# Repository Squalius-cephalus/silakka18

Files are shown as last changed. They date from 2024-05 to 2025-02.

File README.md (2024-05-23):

# Silakka18
RP2040 based macropad with hotswap sockets. Microcontroller uses QMK firmware with Vial support. Based on the [Silli18](https://github.com/Squalius-cephalus/silli18 "Silli18") project, but the firmware is not compatible between them.

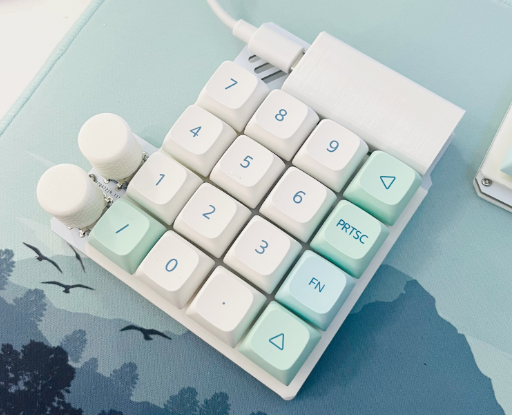
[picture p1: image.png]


## Bill of materials

 - 1 x PCB
 - 1 x Pin compatible Raspberry Pi Pico
 - 1 x 3D printed bottom plate
 - 1 x 3D printed top plate
 - 2 x EC11 Rotary encoders
 - 16 x MX style mechanical switches
 - 16 x MX compatible keycaps
 - 16 x Kailh Hotswap Sockets
 - 8 x M2 4mm bolt
 - 8 x M2 brass inserts 
 - 8x Rubber feet

## TODO

 1. Make build guide

PCB design uses footprints from [ScottoKeebs](https://github.com/joe-scotto/scottokeebs/tree/main/Extras/ScottoKicad "ScottoKeebs") and [kbd library.](https://github.com/foostan/kbd "kbd library.")

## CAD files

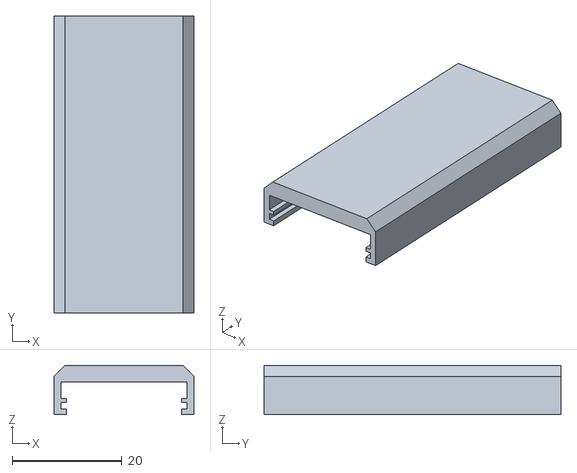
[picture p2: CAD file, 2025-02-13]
stl/raspberry_pi_pico_cover.stl
25.4 x 54.0 x 9.00

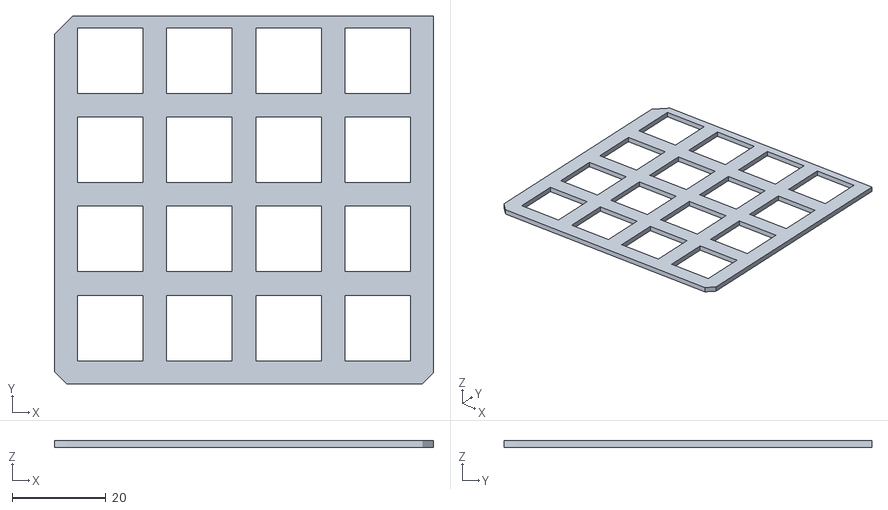
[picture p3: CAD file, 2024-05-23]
stl/silakka18_top.stl
81.0 x 78.5 x 1.50

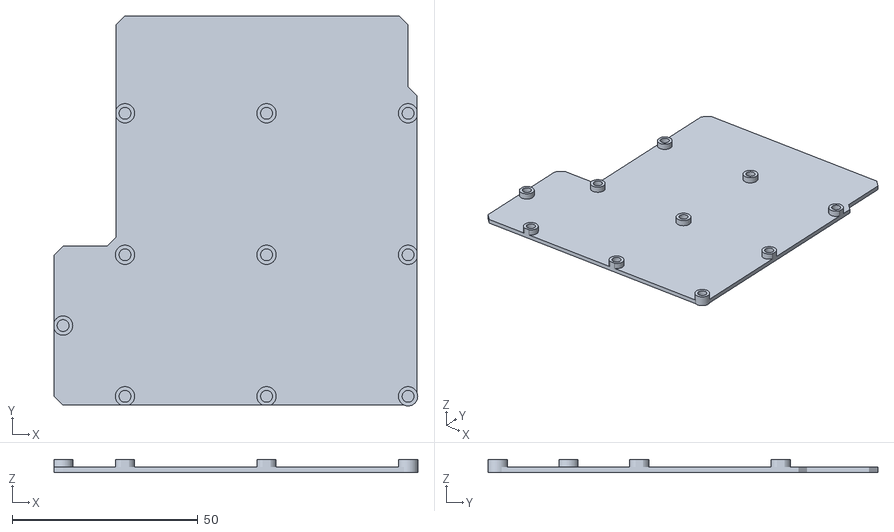
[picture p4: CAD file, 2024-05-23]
stl/silakka18_bottom.stl
97.9 x 105.0 x 3.57

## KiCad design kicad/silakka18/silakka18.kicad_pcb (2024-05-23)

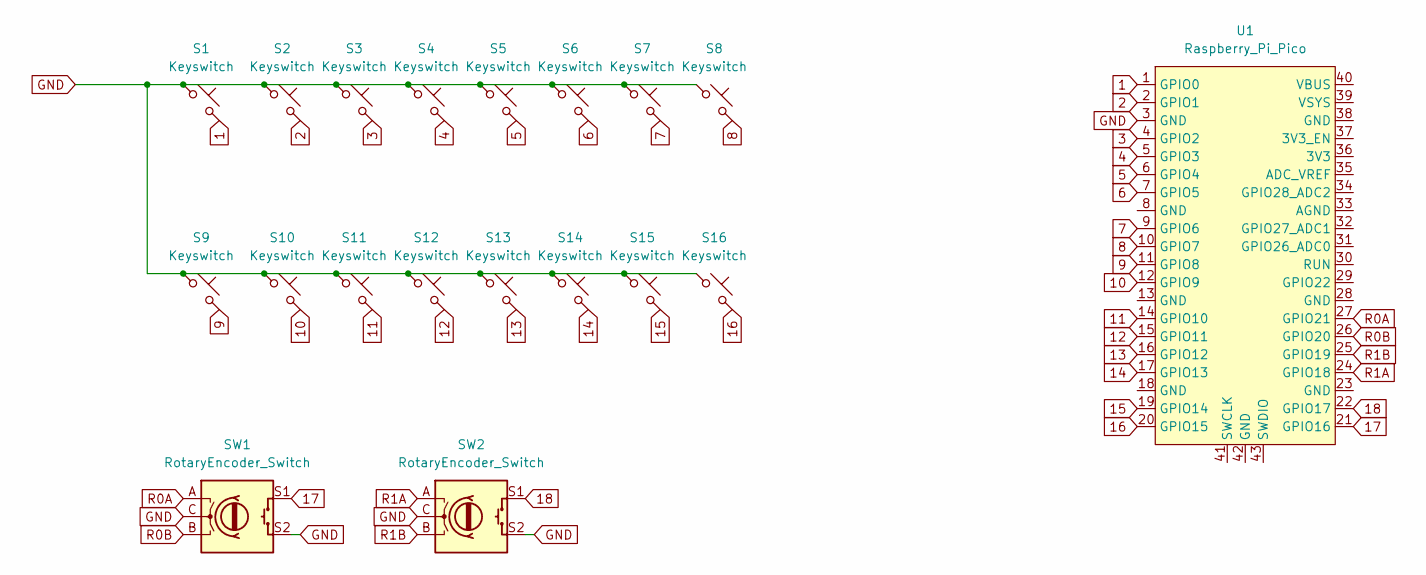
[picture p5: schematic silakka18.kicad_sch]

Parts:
S1, S2, S3, S4, S5, S6, S7, S8, S9, S10, S11, S12, S13, S14, S15, S16: Keyswitch; CherryMX_Hotswap
SW1, SW2: RotaryEncoder_Switch; RotaryEncoder_EC11
U1: Raspberry_Pi_Pico

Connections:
1: S1.2, U1.1 (GPIO0)
2: S2.2, U1.2 (GPIO1)
3: S3.2, U1.4 (GPIO2)
4: S4.2, U1.5 (GPIO3)
5: S5.2, U1.6 (GPIO4)
6: S6.2, U1.7 (GPIO5)
7: S7.2, U1.9 (GPIO6)
8: S8.2, U1.10 (GPIO7)
9: S9.2, U1.11 (GPIO8)
10: S10.2, U1.12 (GPIO9)
11: S11.2, U1.14 (GPIO10)
12: S12.2, U1.15 (GPIO11)
13: S13.2, U1.16 (GPIO12)
14: S14.2, U1.17 (GPIO13)
15: S15.2, U1.19 (GPIO14)
16: S16.2, U1.20 (GPIO15)
17: SW1.S1, U1.21 (GPIO16)
18: SW2.S1, U1.22 (GPIO17)
GND: S1.1, S2.1, S3.1, S4.1, S5.1, S6.1, S7.1, S8.1, S9.1, S10.1, S11.1, S12.1, S13.1, S14.1, S15.1, S16.1, SW1.C, SW1.S2, SW2.C, SW2.S2, U1.3 (GND)
R0A: SW1.A, U1.27 (GPIO21)
R0B: SW1.B, U1.26 (GPIO20)
R1A: SW2.A, U1.24 (GPIO18)
R1B: SW2.B, U1.25 (GPIO19)

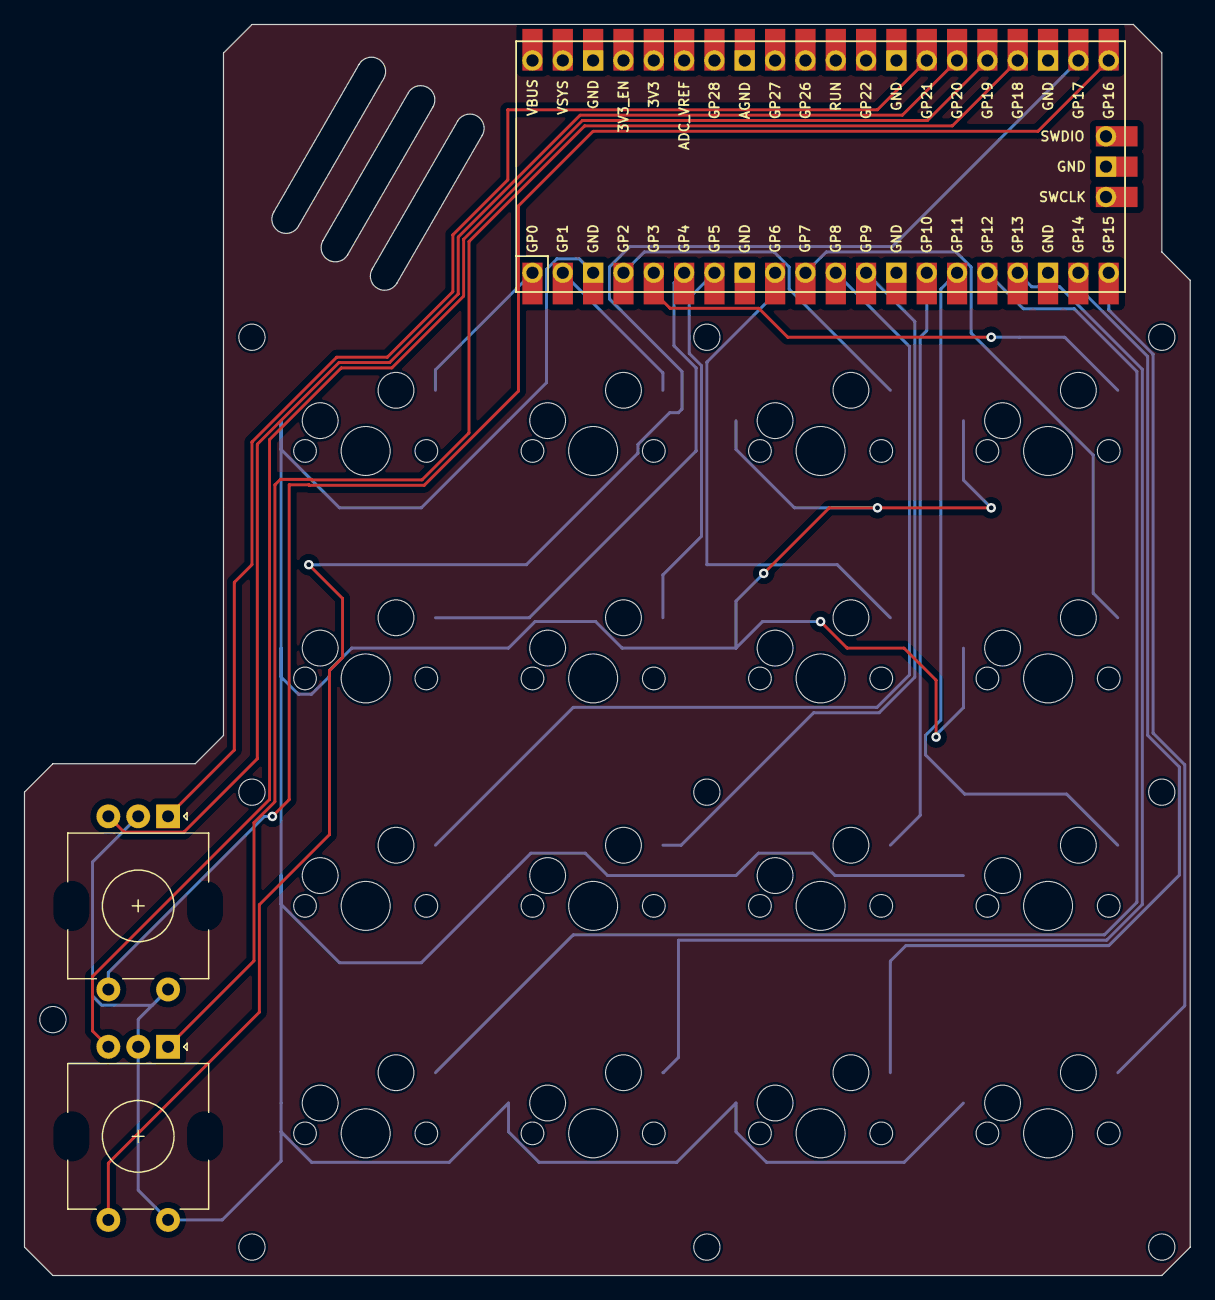
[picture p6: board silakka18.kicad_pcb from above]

Board: 2 copper layers, 97.6 x 104.8 mm, 19 parts (0 on the bottom side), 23 nets.

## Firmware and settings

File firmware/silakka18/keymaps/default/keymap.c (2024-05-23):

// Copyright 2023 QMK
// SPDX-License-Identifier: GPL-2.0-or-later

#include QMK_KEYBOARD_H

const uint16_t PROGMEM keymaps[][MATRIX_ROWS][MATRIX_COLS] = {
    /*
     * ┌───┬───┬───┬───┐
     * │ 7 │ 8 │ 9 │ENT│
     * ├───┼───┼───┤───┤
     * │ 4 │ 5 │ 6 │ - │
     * ├───┼───┼───┼───┤
     * │ 1 │ 2 │ 3 │ + │
     * ├───┼───┼───┤───┤
     * │ / │ 0 │ . │SFT│
     * └───┴───┴───┴───┘
     * ┌────┐ ┌────┐
     * │MUTE│ │STOP│
     * └────┘ └────┘
     */
    [0] = LAYOUT_numpad_4x4_2(
        KC_P7,   KC_P8,   KC_P9,   KC_KP_ENTER,
        KC_P4,   KC_P5,   KC_P6,   KC_KP_MINUS,
        KC_P1,   KC_P2,   KC_P3,   KC_KP_PLUS,
        KC_PSLS,   KC_P0,   KC_KP_DOT,   KC_LSFT,
        KC_AUDIO_MUTE,   KC_MPLY
    )
};

#if defined(ENCODER_MAP_ENABLE)
const uint16_t PROGMEM encoder_map[][NUM_ENCODERS][NUM_DIRECTIONS] = {
    [0] = { ENCODER_CCW_CW(KC_VOLD, KC_VOLU), ENCODER_CCW_CW(KC_MEDIA_PREV_TRACK, KC_MEDIA_NEXT_TRACK)  },

};
#endif
